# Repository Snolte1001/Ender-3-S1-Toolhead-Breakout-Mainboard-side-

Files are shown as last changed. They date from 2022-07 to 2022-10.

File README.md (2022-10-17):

# Ender-3-S1-Toolhead-Breakout-Mainboard-side-
Ender 3 S1 Toolhead Breakout (Mainboard side)

Breakout PCB for Ender 3 S1 toolhead cable mainboard side.  
Allows the use of another mainboard without having to change the original cable.

NOTE !
Due to the circuit in the toolhead, it is only possible to use 24V fan, because fan + and heat cartridge share the same wire ! 

All connectors JST-XH series.  
Pin header for flat ribbon cable TRU COMPONENTS 1589712 or compatible with 2mm pitch and 30 pin

The .zip file is ready to be uploaded to your trusted PCB manufacturer. PCP Way and Aisler are tested.

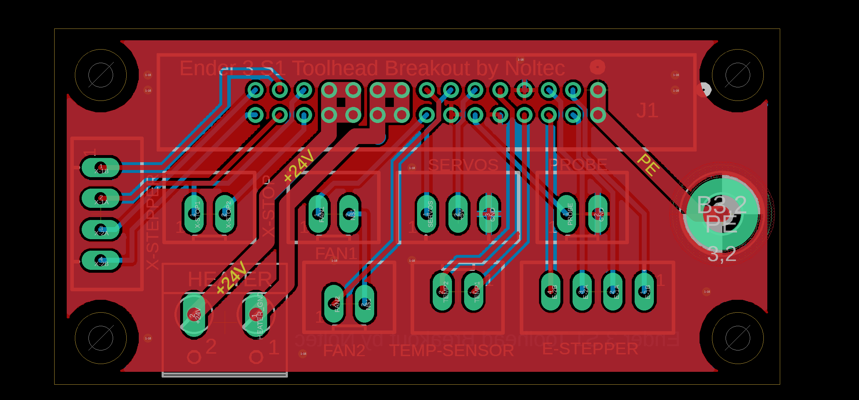
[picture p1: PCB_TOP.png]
  
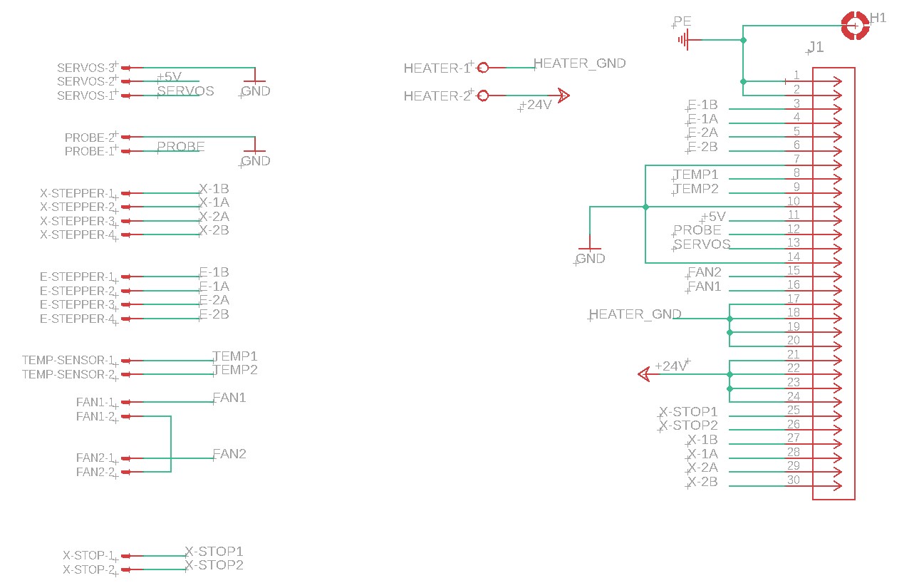
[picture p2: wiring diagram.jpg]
  
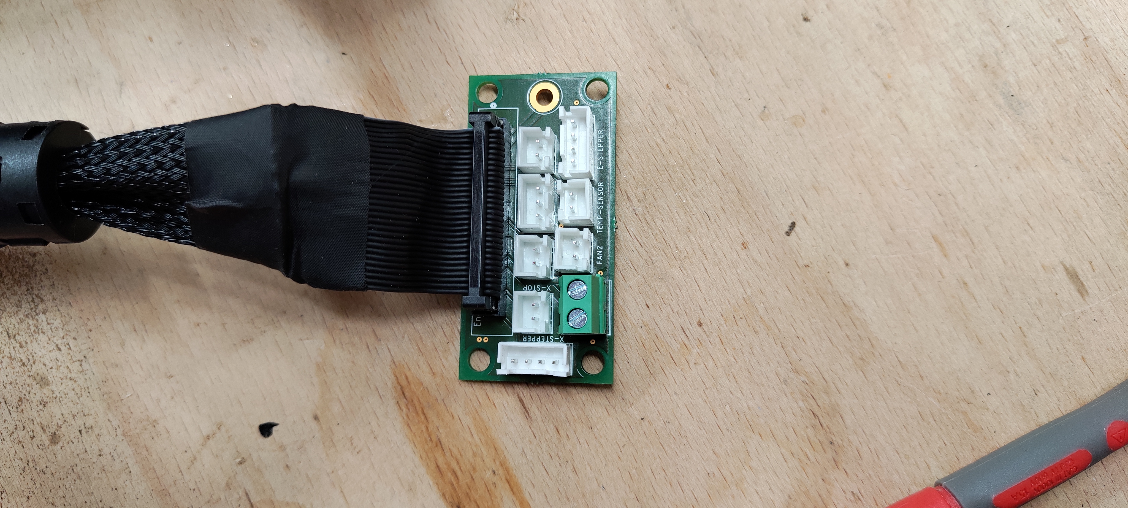
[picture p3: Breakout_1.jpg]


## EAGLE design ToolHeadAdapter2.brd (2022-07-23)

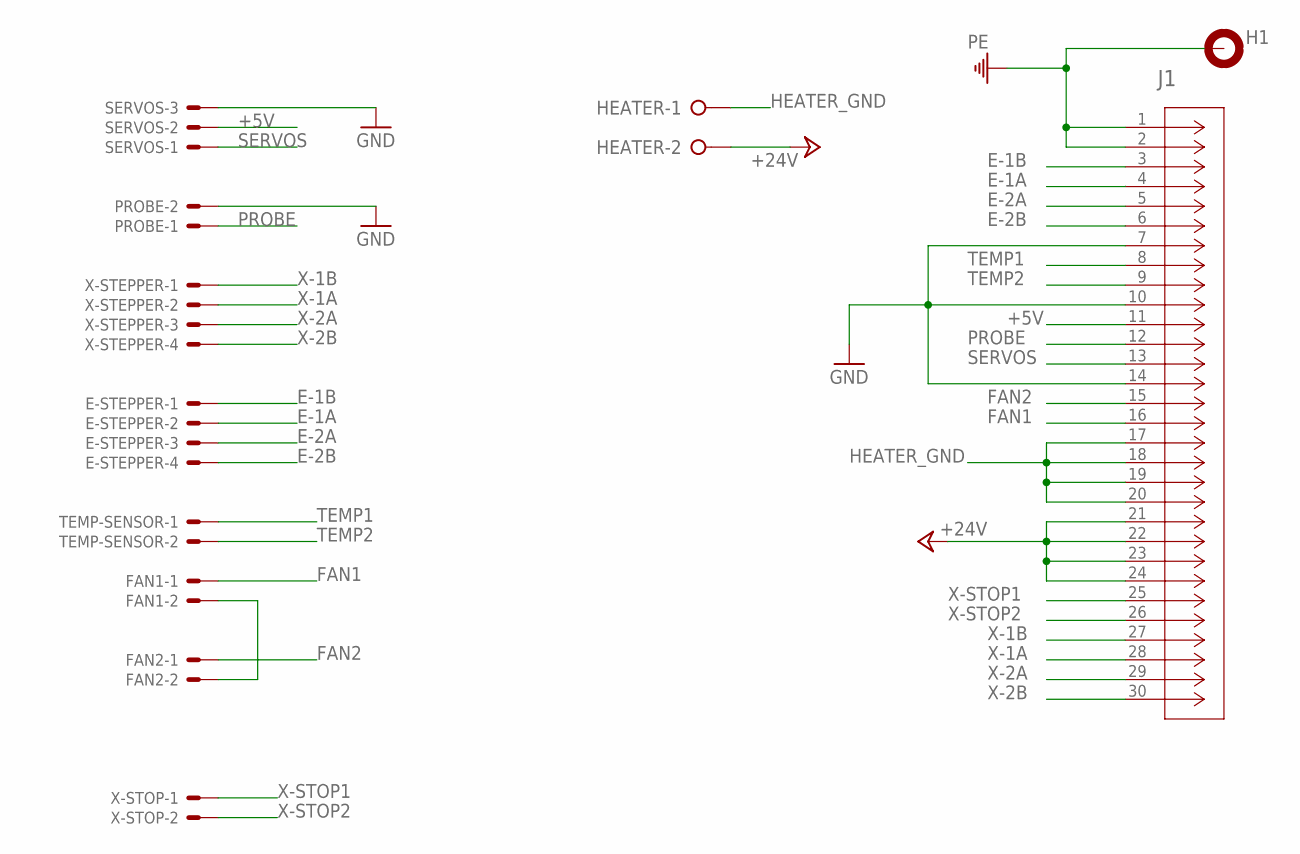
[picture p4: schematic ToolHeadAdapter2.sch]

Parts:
E-STEPPER: JST-XH-04-PIN-LONG-PAD; JST-XH-04-PACKAGE-LONG-PAD
FAN1, FAN2: JST-XH-02-PIN-LONG-PAD; JST-XH-02-PACKAGE-LONG-PAD
H1: MOUNT-PAD-ROUND3.2; 3,2-PAD
HEATER: W237-02P; W237-132
J1: EHT-115-01-S-D; CONN30_15-01-F-D_SAI
PROBE: JST-XH-02-PIN-LONG-PAD; JST-XH-02-PACKAGE-LONG-PAD
SERVOS: JST-XH-03-PIN-LONG-PAD; JST-XH-03-PACKAGE-LONG-PAD
TEMP-SENSOR: JST-XH-02-PIN-LONG-PAD; JST-XH-02-PACKAGE-LONG-PAD
X-STEPPER: JST-XH-04-PIN-LONG-PAD; JST-XH-04-PACKAGE-LONG-PAD
X-STOP: JST-XH-02-PIN-LONG-PAD; JST-XH-02-PACKAGE-LONG-PAD

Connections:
+5V: J1.11, SERVOS.2
+24V: HEATER.2, J1.21, J1.22, J1.23, J1.24
E-1A: E-STEPPER.2, J1.4
E-1B: E-STEPPER.1, J1.3
E-2A: E-STEPPER.3, J1.5
E-2B: E-STEPPER.4, J1.6
FAN1: FAN1.1, J1.16
FAN2: FAN2.1, J1.15
GND: J1.7, J1.10, J1.14, PROBE.2, SERVOS.3
HEATER_GND: HEATER.1, J1.17, J1.18, J1.19, J1.20
unnamed: FAN1.2, FAN2.2
PE: H1.B3,2, J1.1, J1.2
PROBE: J1.12, PROBE.1
SERVOS: J1.13, SERVOS.1
TEMP1: J1.8, TEMP-SENSOR.1
TEMP2: J1.9, TEMP-SENSOR.2
X-1A: J1.28, X-STEPPER.2
X-1B: J1.27, X-STEPPER.1
X-2A: J1.29, X-STEPPER.3
X-2B: J1.30, X-STEPPER.4
X-STOP1: J1.25, X-STOP.1
X-STOP2: J1.26, X-STOP.2

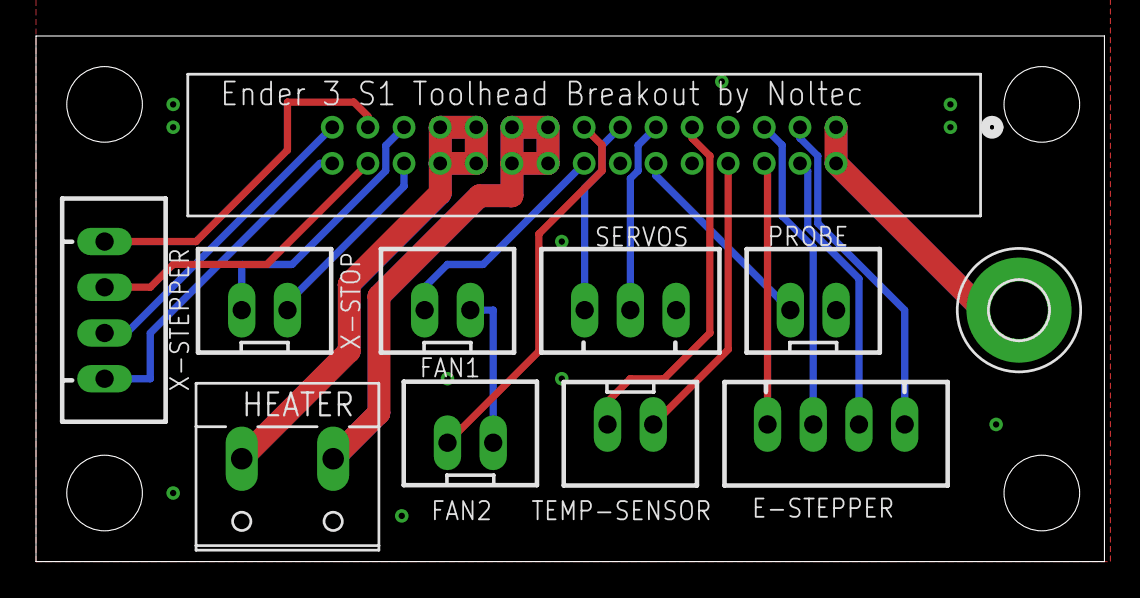
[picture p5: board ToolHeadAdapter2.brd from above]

Board: 2 copper layers, 59.4 x 29.2 mm, 11 parts (0 on the bottom side), 22 nets.

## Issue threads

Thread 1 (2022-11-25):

About your EMI CRTouch findings...

mhaas, 2022-11-25:
Hi Stefan,

I am collecting some information on the broken ABL on the S1 over here: https://github.com/mhaas/ender-3-s1/wiki/Automatic-Bed-Leveling-Issues

I found your findings on EMI super interesting; I have integrated your notes here: https://github.com/mhaas/ender-3-s1/wiki/Automatic-Bed-Leveling-Issues#the-emi-hypothesis

I think building the firmware with `PROBING_ESTEPPERS_OFF` and `PROBING_STEPPERS_OFF` might fix/workaround this issue. I might try this on the weekend.

BTW, feel free to update/edit the wiki as you see fit!

Again, thanks for sharing your findings!

Michael

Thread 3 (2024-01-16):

Different fan power wiring on Ender 5 S1

chaserhkj, 2024-01-16:
I'm on an Ender 5 S1. The mainboard and tool headboard look exactly the same as Ender 3 S1, so I thought I could use this breakout board for switching my mainboard to some BTT boards.

However when I tested the connections out of caution using a multimeter, I found out that pin 22 on my tool headboard is not connected to the heater's 24V supply, it seems to be connected to the common pins of the fans' connectors. This is probably meant to be used as the fan's power supply.

Connecting them will probably still work as long as the fans use the same power supply as the heaters. However, a separate connection will enable fans of different voltages to be used (although the two fans still need to be in the same voltage among themselves).

I am not sure if this is an error in this project, or if Creality revised their designs. But I want to make a breakout board with the 10-pin connector as well, so I might do this in another project repository.

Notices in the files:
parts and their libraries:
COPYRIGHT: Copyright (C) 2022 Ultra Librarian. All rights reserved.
